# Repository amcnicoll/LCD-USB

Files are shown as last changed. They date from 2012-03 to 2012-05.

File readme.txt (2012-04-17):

***/ Summary /***

This code is for the LCD-USB project, which is a personal project aimed at producing two USB-controlled LCD readouts for displaying information on the outside of a computer case. It consists of the Windows USB driver, the Windows communication binary (called the "control utility") and the AVR code.

The free V-USB library (http://www.obdev.at/products/vusb/index.html) is used for USB communications from our AVR; this is paired with libusb (http://www.libusb.org/) on Windows, which gives access to useful USB functions through C. The library used for LCD control on the AVR is a very heavily modified version of one from Scienceprog.com; it has little functionality beyond what we need, and supports two completely independent channels. The rest of the code is original and is more or less up for grabs until we settle on some sort of license...

EAGLE files for the corresponding board can be found under "board." As this project wraps up I'll post a BOM and assembly pictures. The SVG is meant for use in a laser cutter; I spray-paint copper-clad boards and engrave away the trace patterns, and etch what's left. You can also invert the SVG and use the more traditional laser printer style, although its complexity might lead to some headaches.

***/ Control Utility Usage /***

Note that all of these functions can be accessed using the include gui.exe, and that you must install the Windows driver to use this device at all.

usblcd.exe [COMMAND] [ARGUMENT]

Commands:
0		// Turn backlights off
1		// Turn backlights on
2		// Clear both screens
3 [0-255]	// Control fan channel 1. Follow by value from 0-255 representing speed.
4 [0-255]	// Control fan channel 2. Follow by value from 0-255 representing speed.
5 [0-255]	// Control lights. Follow by value from 0-255 representing brightness.
6 [String]	// Send string to first line on A. Argument is encoded string.
7 [String]	// Send string to second line on A. Argument is encoded string.	
8 [String]	// Send string to first line on B. Argument is encoded string.
9 [String]	// Send string to second line on B. Argument is encoded string.

***/ Encoding /***

Strings sent to the control utility are send as expected, with two important exceptions:
- Special characters can be accessed with the escape character "~" followed by a number, corresponding to:
	0: Space
	1-5: Progress blocks from 1/5 to full
	6: Left bookend (progress bar border)
	7: Right bookend 
- No spaces may be sent included; this splits the string up into multiple arguments. Instead use "~0".

TODO
- General robustness on control util input

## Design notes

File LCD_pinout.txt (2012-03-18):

Ground
VCC (+3.3 to +5V)
Contrast adjustment (VO)
Register Select (RS). RS=0: Command, RS=1: Data
Read/Write (R/W). R/W=0: Write, R/W=1: Read
Clock (Enable). Falling edge triggered
Bit 0 (Not used in 4-bit operation)
Bit 1 (Not used in 4-bit operation)
Bit 2 (Not used in 4-bit operation)
Bit 3 (Not used in 4-bit operation)
Bit 4
Bit 5
Bit 6
Bit 7
Backlight Anode (+)
Backlight Cathode (-)

Pins from left, looking at LCD.

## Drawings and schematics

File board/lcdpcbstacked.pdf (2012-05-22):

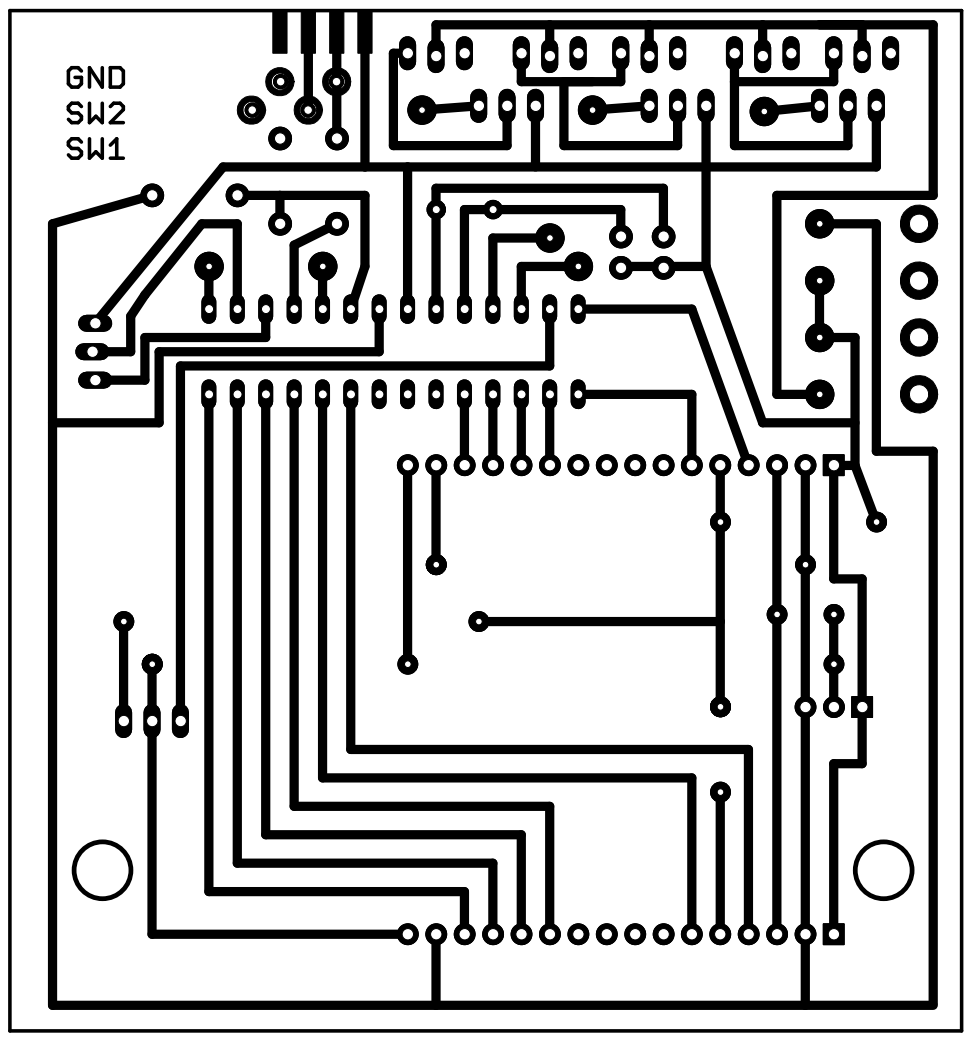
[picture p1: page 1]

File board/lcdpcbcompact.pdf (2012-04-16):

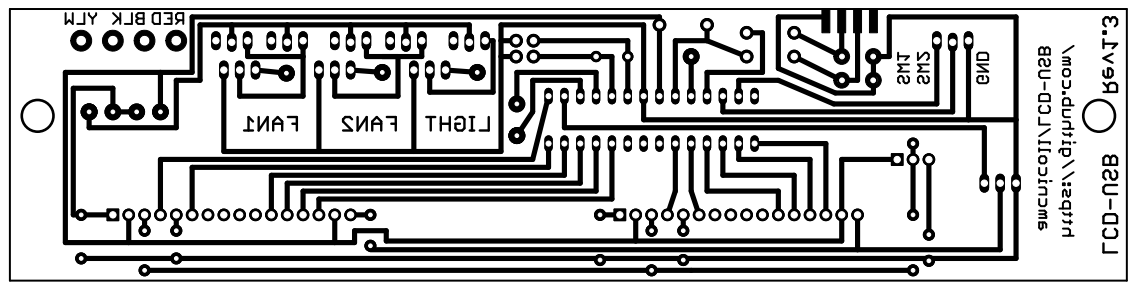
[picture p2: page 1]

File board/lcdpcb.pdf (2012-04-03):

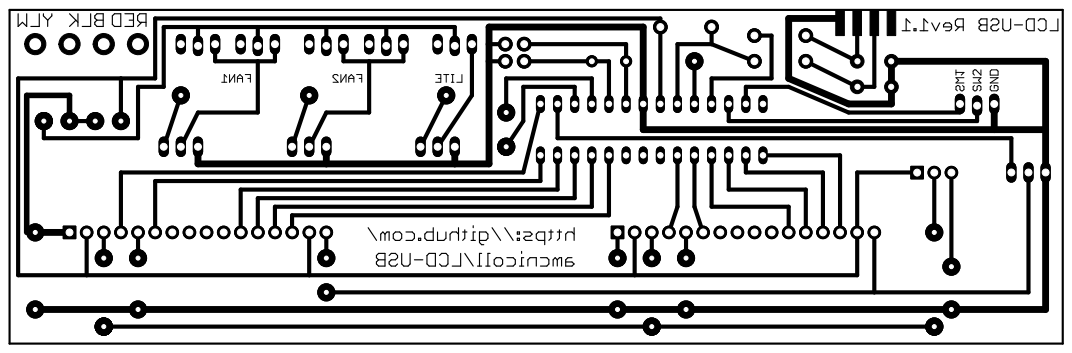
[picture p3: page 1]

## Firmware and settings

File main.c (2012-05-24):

#include <avr/io.h>
#include <inttypes.h>
#include "lcd_lib_4bit.h"
#include <util/delay.h>
#include <stdlib.h>
#include <avr/interrupt.h>
#include <avr/wdt.h>

#include "usbdrv.h"
#include "config.h"

// Macros
#define set_low(port,pin) port &= ~(1<<pin)
#define set_high(port,pin) port |= (1<<pin)
#define set_input(portdir,pin) portdir &= ~(1<<pin)
#define set_output(portdir,pin) portdir |= (1<<pin)

// Used for ongoing transmissions
uint8_t buff[16];					// Build transmitted strings here
uint8_t addr;

// Predefined messages:  "LCD Ready!" and "USB Ready!"
uint8_t lcdinit[16] = {76, 67, 68, 0, 82, 101, 97, 100, 121, 33, 0, 0, 0, 0, 0, 0};
uint8_t usbinit[16] = {85, 83, 66, 0, 82, 101, 97, 100, 121, 33, 0, 0, 0, 0, 0, 0};

int main(void)
{
	// Lights, backlights, and fan initialization
	set_output(F1DD,F1PIN);
	set_output(F2DD,F2PIN);
	set_output(LDD,LPIN);
	set_output(BLDD,BLPIN);
	set_high(LPORT,BLPIN);

	TCCR0A = 0xA3;					// Timer0, channels A and B to Fast PWM Mode
	TCCR2A = 0x23;					// Timer2, channel B to Fast PWM Mode
	TCCR0B = 0x05;					// Prescaler is 1024 to give MOSFETS plenty of time
	TCCR2B = 0x07;
	OCR0A = 0xFF;					// Rev up fans for 2s to avoid stalling
	OCR0B = 0xFF;
	_delay_ms(2000);
	OCR0A = 0x7F;					// Reduce fans to 50% power (127)
	OCR0B = 0x7F;
	uchar i;
	for (i=0;i<3;i++){				// Blink lights to signal life
		OCR2B = 0xFF;
		_delay_ms(200);
		OCR2B = 0x00;
		_delay_ms(200);
	}
	OCR2B = 0x14;					// Init lights at low brightness (20)


	// LCD initialization
	_delay_ms(200);
	CHA_LCDinit();
	CHA_LCDclr();
	CHB_LCDinit();
	CHB_LCDclr();
	CHA_LCDstringLine(lcdinit,0);	// LCD ready to go!

	// USB initialization
    wdt_enable(WDTO_1S); 			// Enable 1s watchdog timer
    usbInit();
    usbDeviceDisconnect(); 			// Enforce re-enumeration
    for(i = 0; i<200; i++) { 		// Wait 200 ms
        wdt_reset();				// Keep the watchdog happy
        _delay_ms(1);
    }
    usbDeviceConnect();
    sei(); 							// Enable interrupts after re-enumeration
    CHB_LCDstringLine(usbinit,0);	// USB ready to go!

    while(1) {						// Feed watchdog and poll USB forever
        wdt_reset();
        usbPoll();
    }

	return 0;
}

// Automagically called upon receiving a USB control message
USB_PUBLIC uchar usbFunctionSetup(uchar data[8]) {

	// Clean up the data we received
    usbRequest_t *rq = (void *)data;
	uchar outputID;
	int cmdID;
	outputID = (rq->bRequest);
	cmdID = (rq->wValue.bytes[0]);

	// LCD screen related commands
	if (outputID==BACKLIGHT_OFF)			// 0: Turn backlights off
		set_low(BLPORT,BLPIN);
	else if(outputID==BACKLIGHT_ON)			// 1: Turn backlights on
		set_high(BLPORT,BLPIN);
	else if(outputID==2){					// 2: Clear both displays
		CHA_LCDclr();
		CHB_LCDclr();
	}

	// Fan and light (PWM) related commands
	else if(outputID==FAN1_SPEED){			// 3: Adjust fan 1 speed
		if(cmdID==0)
			TCCR0A = TCCR0A&0x7F;			// Turn off completely if we got a zero
		else{
			OCR0A = cmdID;					// Take PWM value
			TCCR0A = TCCR0A|0x80;			// Make sure this channel PWM is on
		}
	}
	else if(outputID==FAN2_SPEED){			// 4: Adjust fan 2 speed
		if(cmdID==0)
			TCCR0A = TCCR0A&0xDF;			// Turn off completely if we got a zero
		else{
			OCR0B = cmdID;					// Take PWM value
			TCCR0A = TCCR0A|0x20;			// Make sure this channel PWM is on
		}
	}
	else if(outputID==LIGHT_SPEED){			// 5: Adjust light speed
		if(cmdID==0)
			TCCR2A = TCCR2A&0xDF;			// Turn off completely if we got a zero
		else{
			OCR2B = cmdID;					// Take PWM value
			TCCR2A = TCCR2A|0x20;			// Make sure this channel PWM is on
		}
	}

	// LCD text/comms related commands
	else if(outputID==POST_LINEA0)			// 6: Post buffer to LCD A, line 0
		CHA_LCDstringLine(buff,0);
	else if(outputID==POST_LINEA1)			// 7: Post buffer to LCD A, line 1
		CHA_LCDstringLine(buff,1);
	else if(outputID==POST_LINEB0)			// 8: Post buffer to LCD B, line 0
		CHB_LCDstringLine(buff,0);
	else if (outputID==POST_LINEB1)			// 9: Post buffer to LCD B, line 1
		CHB_LCDstringLine(buff,1);
	else if(outputID==INIT_TRANSMIT)		// 10: String incoming. Reset buffer index.
		addr = 0;
	else if(outputID==RCV_CHAR){			// 11: Got a char. Store it in the buffer.
		buff[addr] = cmdID;
		addr++;
	}

	return 0;
}

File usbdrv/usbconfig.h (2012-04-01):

/* Name: usbconfig.h
 * Project: V-USB, virtual USB port for Atmel's(r) AVR(r) microcontrollers
 * Author: Christian Starkjohann
 * Creation Date: 2005-04-01
 * Tabsize: 4
 * Copyright: (c) 2005 by OBJECTIVE DEVELOPMENT Software GmbH
 * License: GNU GPL v2 (see License.txt), GNU GPL v3 or proprietary (CommercialLicense.txt)
 * This Revision: $Id$
 */

#ifndef __usbconfig_h_included__
#define __usbconfig_h_included__

/*
General Description:
This file is an example configuration (with inline documentation) for the USB
driver. It configures V-USB for USB D+ connected to Port D bit 2 (which is
also hardware interrupt 0 on many devices) and USB D- to Port D bit 4. You may
wire the lines to any other port, as long as D+ is also wired to INT0 (or any
other hardware interrupt, as long as it is the highest level interrupt, see
section at the end of this file).
+ To create your own usbconfig.h file, copy this file to your project's
+ firmware source directory) and rename it to "usbconfig.h".
+ Then edit it accordingly.
*/

/* ---------------------------- Hardware Config ---------------------------- */

#define USB_CFG_IOPORTNAME      D
/* This is the port where the USB bus is connected. When you configure it to
 * "B", the registers PORTB, PINB and DDRB will be used.
 */
#define USB_CFG_DMINUS_BIT      4
/* This is the bit number in USB_CFG_IOPORT where the USB D- line is connected.
 * This may be any bit in the port.
 */
#define USB_CFG_DPLUS_BIT       2
/* This is the bit number in USB_CFG_IOPORT where the USB D+ line is connected.
 * This may be any bit in the port. Please note that D+ must also be connected
 * to interrupt pin INT0! [You can also use other interrupts, see section
 * "Optional MCU Description" below, or you can connect D- to the interrupt, as
 * it is required if you use the USB_COUNT_SOF feature. If you use D- for the
 * interrupt, the USB interrupt will also be triggered at Start-Of-Frame
 * markers every millisecond.]
 */
#define USB_CFG_CLOCK_KHZ       20000
/* Clock rate of the AVR in kHz. Legal values are 12000, 12800, 15000, 16000,
 * 16500, 18000 and 20000. The 12.8 MHz and 16.5 MHz versions of the code
 * require no crystal, they tolerate +/- 1% deviation from the nominal
 * frequency. All other rates require a precision of 2000 ppm and thus a
 * crystal!
 * Since F_CPU should be defined to your actual clock rate anyway, you should
 * not need to modify this setting.
 */
#define USB_CFG_CHECK_CRC       0
/* Define this to 1 if you want that the driver checks integrity of incoming
 * data packets (CRC checks). CRC checks cost quite a bit of code size and are
 * currently only available for 18 MHz crystal clock. You must choose
 * USB_CFG_CLOCK_KHZ = 18000 if you enable this option.
 */

/* ----------------------- Optional Hardware Config ------------------------ */

/* #define USB_CFG_PULLUP_IOPORTNAME   D */
/* If you connect the 1.5k pullup resistor from D- to a port pin instead of
 * V+, you can connect and disconnect the device from firmware by calling
 * the macros usbDeviceConnect() and usbDeviceDisconnect() (see usbdrv.h).
 * This constant defines the port on which the pullup resistor is connected.
 */
/* #define USB_CFG_PULLUP_BIT          4 */
/* This constant defines the bit number in USB_CFG_PULLUP_IOPORT (defined
 * above) where the 1.5k pullup resistor is connected. See description
 * above for details.
 */

/* --------------------------- Functional Range ---------------------------- */
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

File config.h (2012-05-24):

/*
 * Fan/light pins and communication commands here!
 * USB configuration (data pins, device ID) is in usbconfig.h
 * LCD configuration (pins, ports) is in lcd_lib_4bit.h
 *
 *  Created on: Apr 2, 2012
 *      Author: Anthony McNicoll
 */

#ifndef CONFIG_H_
#define CONFIG_H_

// Pins
#define F1PIN	5
#define F2PIN	6
#define LPIN	3
#define BLPIN	7

// Ports
#define F1PORT	PORTD
#define F2PORT	PORTD
#define LPORT	PORTD
#define BLPORT	PORTD

// Data directions
#define F1DD	DDRD
#define F2DD	DDRD
#define LDD		DDRD
#define BLDD	DDRD

// Commands from control utility
#define BACKLIGHT_OFF	0
#define BACKLIGHT_ON	1
#define CLEAR			1
#define FAN1_SPEED		3
#define FAN2_SPEED		4
#define LIGHT_SPEED		5
#define POST_LINEA0		6
#define POST_LINEA1		7
#define POST_LINEB0		8
#define POST_LINEB1		9
#define INIT_TRANSMIT	10
#define RCV_CHAR		11

#endif /* CONFIG_H_ */

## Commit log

2012-03-25 Updated to work with new ATMega328P chip, now have 2 LCD's wired in parallel.
2012-03-25 First version incorporating USB-V libraries; prints a "Recieved" to LCD when sent a 1 from sister program (yet to be committed)
2012-03-26 Started adding digital and PWM outputs
2012-04-01 Added control GUI. Nearly last revision of code before complete parametrization.
    [lcdpcb.brd]
2012-04-02 Finished first revision of board.
    [lcdpcb.brd]
2012-04-03 Revision 1.1 of board - spaced fan headers more conveniently, added more room for MOSFET heatsinks.
    [lcdpcb.brd]
2012-04-03 First full, working release. Added a config file to help with pin assignments and legibility.
2012-04-05 Compact version of the board, designed for LCD's with pins along the bottom (Futurlec red on black). LCD should hover over components.
    [lcdpcbcompact.brd]
2012-04-06 Increased trace width to make home etching easier.
    [lcdpcbcompact.brd]
2012-04-08 Mirrored SVG for use in laser cutter + paint etching.
2012-04-16 Changed MOSFET locations so they can fold under screens, and updated SVG to preserve non-clad hole centers.
    [lcdpcbcompact.brd]
2012-04-19 Bugfix: Fan 2 would not respond to a "0" PWM value due to wrong bitmask.
    [config.h, main.c]
2012-05-11 love from james
    [lcdpcbstacked.brd]
2012-05-22 Finished "stacked" board configuration and created SVG for laser engraving
    [lcdpcbstacked.brd]
2012-05-24 Updated missing trace and code to reflect stacked board
    [lcdpcbstacked.brd]
